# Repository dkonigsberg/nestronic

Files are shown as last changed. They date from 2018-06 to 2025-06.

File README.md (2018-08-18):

# Nestronic Game Music Synthesizer Alarm Clock

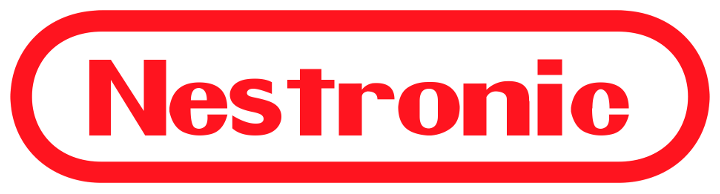
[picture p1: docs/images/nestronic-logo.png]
Nestronic


## Introduction

A good overview of the project can be found in these blog posts:
* [Introducing the Nestronic](http://hecgeek.blogspot.com/2018/02/nestronic-1.html)
* [Nestronic System Architecture](http://hecgeek.blogspot.com/2018/03/nestronic-2.html)
* [Building the Nestronic Prototype](http://hecgeek.blogspot.com/2018/05/nestronic-3.html)
* [Nestronic Input Board](http://hecgeek.blogspot.com/2018/07/nestronic-4.html)

A few videos demonstrating the project are here:
* [First end-to-end test](https://www.youtube.com/watch?v=97jic_WRrwY)
* [DuckTails!](https://www.youtube.com/watch?v=eafaFr9Q_rU)
* [First prototype assembled and working!](https://www.youtube.com/watch?v=izMFPKmD5ZU)
* [Completed case, buttons, and Blaster Master!](https://www.youtube.com/watch?v=pXp97wzkQEE)
* [Nestronic Complete Assembly](https://www.youtube.com/watch?v=UlO0NQTAaJU)

## Project Layout

### Hardware
The "hardware" directory contains [KiCad](http://kicad-pcb.org/) projects
with the complete circuit schematics, bill-of-materials, and
PCB layouts.

There are two circuit boards, the main board and the input board.
The main board contains the majority of the system, while the input
board handles buttons and anything else that needs to be placed on
the top shell of the enclosure.

### Software
The "software" directory contains all the source code for the firmware
that runs on the hardware. The "2a03" subdirectory contains code for
the RP2A03 CPU (a.k.a. NES APU), while the "esp32" subdirectory contains
code for the modern ESP32 microcontroller that drives the rest of the
system.

### Models
The "models" directory contains any CAD models and related resources
necessary to physically assemble the project. This may be sparse for now,
but will be filled out over time.

## Credits
ESP32 schematic symbols and footprints originally from:
https://github.com/adamjvr/ESP32-kiCAD-Footprints

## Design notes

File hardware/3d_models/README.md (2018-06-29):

# 3D Component Models

## Introduction

The 3D models used by the components in these schematics come from a variety
of sources. Some were created for this project, using KiCad's library
scripts and/or FreeCAD directly. Many others were downloaded from component
manufacturer websites.

Some manufacturers have a habit of freely distributing 3D models for their
components with attached notes saying that they shall not be redistributed.
These notes also often mention that the models are proprietary, confidential,
for personal use only, or something else that would scare you off from
actually admitting that you used them. As such, these models have not been
included in the project repository. Instead, link for downloading them
is provided.

The actual conversion of component models to WRL files is accomplished
with the [KiCad StepUp plugin](https://sourceforge.net/projects/kicadstepup/).

## Model List

The models are listed by base filename. Typical distribution files have
the ".step" extension, while the exported files have the ".wrl" extension.

To include models marked as not redistributable, download them from the
original source and convert using the KiCad StepUp plugin for FreeCAD.
Make sure the original and converted files have the same base name as
listed below.

Due to the incremental nature of project development, this list may include
models for components that are no longer part of the actual board design.

### B2B-PH-SM4-TB
* Status: Not included (Not redistributable)
* Source: http://www.jst-mfg.com/product/licensing_e.php?type=2&series=199&filename=B2B-PH-SM4-TB.zip

### BM06B-SRSS-TB
* Status: Not included (Not redistributable)
* Source: http://www.jst-mfg.com/product/licensing_e.php?type=2&series=231&filename=BM06B-SRSS-TB.zip

### SM06B-SRSS-TB
* Status: Not included (Not redistributable)
* Source: http://www.jst-mfg.com/product/licensing_e.php?type=2&series=231&filename=SM06B-SRSS-TB.zip

### DM3AT-SF-PEJM5
* Status: Not included (Not redistributable)
* Source: https://www.hirose.com/product/en/download_file/key_name/DM3AT-SF-PEJM5/category/Drawing%20(3D)(STEP)/doc_file_id/158358/?item_id=06090031000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

### BU2032SM-BT-GTR
* Status: Included (no terms listed with download)
* Source: http://www.memoryprotectiondevices.com/3d/download.php?pn=BU2032SM-BT-GTR

### CUI_PJ-058AH
* Status: Included (no terms listed with download)
* Source: https://www.cui.com/product/resource/digikey3dmodel/pj-058ah

### CUI_PJ-102AH
* Status: Included (no terms listed with download)
* Source: https://www.cui.com/product/resource/digikey3dmodel/pj-102ah

### P090S-04F15AR1MEG
* Status: Included (no terms listed with download)
* Source: http://www.ttelectronics.com/themes/ttelectronics/datasheets/3d/P090S-04F15AR1MEG.stp

### KiCAD-ESP-WROOM-32
* Status: Included (no terms listed with download)
* Source: https://grabcad.com/library/esp-wroom-32-3d-step-and-iges-models-1

### R-78E-0-5
* Status: Included (Same license as project)
* Source: Created for project using FreeCAD

### SLP4016P16_1.6x4mm_P0.5mm
* Status: Included (Same license as project)
* Source: Created for project using modified KiCad model scripts

### TSL251R
* Status: Included (Same license as project)
* Source: Created for project using FreeCAD

### SOIC-28W_8.636x18.491mm_P1.27mm
* Status: Included (Same license as project)
* Source: Created for project using modified KiCad model scripts

### AMS_TSL2591
* Status: Included (Same license as project)
* Source: Created for project using modified KiCad model scripts
* Notes: Matches general dimensions of component, but not appearance

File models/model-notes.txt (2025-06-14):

Top
---
Positioning touch pad:
X = -1.965 mm
Y = -24.04 mm

Front panel DXF
---------------
Display center is is 6.049mm above panel center
Bezel is 28.46mm (vertical) from panel center

Hardware
--------
Base:
94180A333 x 4
	Heat-Set Inserts for Plastics
	M3 x 0.5 mm Thread Size, 6.4 mm Installed Length
94180A321 x 4
	Heat-Set Inserts for Plastics
	M2.5 x 0.45 mm Thread Size, 3.4 mm Installed Length
92005A118 x 4
	Steel Pan Head Phillips Screw
	M3 x 0.5 mm Thread, 8 mm Long
91166A210 x 4
	Zinc-Plated Steel Washer
	for M3 Screw Size, 3.2 mm ID, 7 mm OD
91420A016 x 4
	Steel Phillips Flat Head Screws
	M2.5 x 0.45 mm Thread, 6 mm Long

Top:
94180A331 x 8
	Heat-Set Inserts for Plastics
	M3 x 0.5 mm Thread Size, 3.8 mm Installed Length
94180A321 x 1
	Heat-Set Inserts for Plastics
	M2.5 x 0.45 mm Thread Size, 3.4 mm Installed Length
92005A116 x 8
	Steel Pan Head Phillips Screw
	M3 x 0.5 mm Thread, 6 mm Long
92005A061 x 1
	Steel Pan Head Phillips Screw
	M2.5 x 0.45 mm Thread, 5 mm Long
91166A210 x 8
	Zinc-Plated Steel Washer
	for M3 Screw Size, 3.2 mm ID, 7 mm OD

Connection:
94180A333 x 4
	Heat-Set Inserts for Plastics
	M3 x 0.5 mm Thread Size, 6.4 mm Installed Length
92005A118 x 4
	Steel Pan Head Phillips Screw
	M3 x 0.5 mm Thread, 8 mm Long

Standard Dimensions
-------------------
M3 x L6.4mm inserts (94180A333)
	Hole diameter: 5.31 mm (M3_L6_4mm_diameter)
	Depth: 6.4 mm (M3_L6_4mm_depth)
	Taper angle: -2.371 deg (M3_L6_4mm_taper)

M3 x L3.8mm inserts (94180A331)
	Hole diameter: 0.213 in (M3_L3_8mm_diameter)
	Depth: 0.157 in (M3_L3_8mm_depth)
	Taper angle: -3.16 deg (M3_L3_8mm_taper)

M2.5 x L3.4mm inserts (94180A321)
	Hole diameter: 0.163 in (M2_5_L3_4mm_diameter)
	Depth: -3.4 mm (M2_5_L3_4mm_depth)
	Taper angle: -2.021 deg (M2_5_L3_4mm_taper)

Printing Notes
--------------
All parts printed on the Ultimaker 3
Prints secured to bed with Magigoo
0.4mm nozzle, unless specified otherwise

All parts, except the thumbwheel, need a 90 degree rotation in Cura
to print with the correct orientation.

base.stl
	- Atomic Filament 2.85mm Gray PLA
	- Ultimaker Breakaway Material (supports)
	- Layer Height: 0.1
	- Infill: 20%
	- Supports: yes (breakaway)
	- Print time: 01d 12h 50min
	- Material used: 116g

top.stl / top-touchpad.stl
	- Touchpad offset: Y = -14.9938 mm
	- Atomic Filament 2.85mm Light Gray v2 PLA (top)
	- Proto-Pasta 2.85mm Conductive PLA (touchpad)
	- Infill: 20%
	- Supports: yes (light gray)

bezel.stl
	- Ultimaker Red PLA
	- Layer Height: 0.1mm
	- Infill: 20%
	- Supports: no

top-speaker-gasket.stl
	- Ultimaker Black TPU 95A
	- Layer Height: 0.2mm
	- Infill: 20%
	- Supports: no

thumbwheel.stl
	- Nozzle: AA 0.25mm
	- Ultimaker Black PLA
	- Layer Height: 0.1mm
	- Infill: 20%
	- Supports: no

button_4way.stl
	- Nozzle: AA 0.25mm
	- Ultimaker Black PLA
	- Layer Height: 0.06mm
	- Infill: 100%
	- Supports: no

button_select.stl (x2)
	- Nozzle: AA 0.25mm
	- Ultimaker Black PLA
	- Layer Height: 0.06mm
	- Infill: 100%
	- Supports: no

button_ab.stl (x2)
	- Nozzle: AA 0.25mm
	- Ultimaker Red PLA
	- Layer Height: 0.06mm
	- Infill: 100%
	- Supports: no

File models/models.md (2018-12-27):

# Nestronic Enclosure Models

## Introduction

This directory contains all the assets necessary to produce the physical
enclosure for the Nestronic. This document explains how to use those
assets, and ultimately how to assemble the enclosure.

## Electronics

### Main Board

The assets for the main circuit board are contained within the "main-board"
project under the top-level "hardware" directory. This board is installed
into the base of the enclosure.

### Input Board

The assets for the input circuit board are contained within the "input-board"
project under the top-level "hardware" directory. This board is installed
into the top of the enclosure.

### Display Module

* Newhaven Display Graphic OLED
* Part number:
    NHD-3.12-25664UCW2 (white),
    NHD-3.12-25664UCB2 (blue), or
    NHD-3.12-25664UCY2 (yellow)
* 3.12" diagonal, 256x64 pixels
* Reference: http://www.newhavendisplay.com/nhd31225664ucw2-p-9583.html
* _**Note:** You will need to solder a 20-pin header onto the display module,
  and will also need to procure a short cable to connect it to a matching
  pin header on the main board._

### Speaker

* CUI Inc. Standard Size Speaker
* Part number: CSS-66668N
* 3.0 W, 8 Ohm, Neodymium Magnet, Paper Cone
* Reference: https://www.cui.com/product/audio/speakers/standard-(41-mm~205-mm)/css-66668n
* _**Note:** You will need to solder a cable with a JST-PH 2-pin plug onto
  the speaker's terminals. One convenient source for this is sold by
  Adafruit as a [battery extension cable](https://www.adafruit.com/product/1131)
  that you can cut the socket off of._

### Connector Cable

* JST Inc. Jumper Cable
* Part number: A06SR06SR30K152B
* JUMPER 06SR-3S - 06SR-3S 6"
* Digi-Key Part number: 455-3015-ND

## Mechanical Hardware

The mechanical hardware is specified in terms of parts that are orderable
from the [McMaster-Carr](https://www.mcmaster.com/) catalog. For the heat-set
inserts, it is probably best to stick to these exact parts. For the other
components, anything of similar specifications should work.

### Heat-Set Inserts
* **Heat-Set Inserts for Plastics**
    * M3 x 0.5 mm Thread Size, 6.4 mm Installed Length
    * Part: 94180A333
    * Quantity: 8
* **Heat-Set Inserts for Plastics**
    * M3 x 0.5 mm Thread Size, 3.8 mm Installed Length
    * Part: 94180A331
    * Quantity: 8
* **Heat-Set Inserts for Plastics**
    * M2.5 x 0.45 mm Thread Size, 3.4 mm Installed Length
    * Part: 94180A321
    * Quantity: 5

### Screws
* **Steel Pan Head Phillips Screw**
    * M3 x 0.5 mm Thread, 8 mm Long
    * Part: 92005A118
    * Quantity: 8
* **Steel Pan Head Phillips Screw**
    * M3 x 0.5 mm Thread, 6 mm Long
    * Part: 92005A116
    * Quantity: 8
* **Steel Phillips Flat Head Screws**
    * M2.5 x 0.45 mm Thread, 6 mm Long
    * Part: 91420A016
    * Quantity: 4
* **Steel Pan Head Phillips Screw**
    * M2.5 x 0.45 mm Thread, 5 mm Long
    * Part: 92005A061
    * Quantity: 1

### Miscellaneous
* **Zinc-Plated Steel Washer**
    * For M3 Screw Size, 3.2 mm ID, 7 mm OD
    * Part: 91166A210
    * Quantity: 8-12
* **Polyethylene Foam Adhesive-Back Bumper**
    * 1/2" OD, 1/8" High
    * Part: 8213K4
    * Quantity: 4
    * _**Note:** Nonslip rubber bumper 8771K81 may alternatively be used._

## 3D Printed Components

The prototype enclosure was printed on an [Ultimaker 3](https://ultimaker.com/en/products/ultimaker-3) using [Cura](https://ultimaker.com/en/products/ultimaker-cura-software) as the slicer.
The print bed was prepared with [Magigoo](https://magigoo.com/) to ensure
bottom layer adhesion during the printing process.
All parts, except for the thumbwheel, need a 90 degree rotation in Cura to
print with the correct orientation.

### Enclosure Shell
These components were printed using a standard 0.4mm AA nozzle, and will
probably look fine if printed with a lower level of detail than specified.

* **Base** (base.stl)
    * Extruder 1: Atomic Filament 2.85mm Gray PLA
    * Extruder 2: Ultimaker Breakaway Material
    * Layer Height: 0.15mm
    * Infill: 20%
    * Supports: yes (Extruder 2)
    * _**Note:** Using a prime tower is highly recommended as a way to reduce
      any oozing caused by the support material."_

* **Top** (top.stl, top-touchpad.stl)
    * Extruder 1: Atomic Filament 2.85mm Light Gray v2 PLA
    * Extruder 2: Proto-Pasta 2.85mm Conductive PLA
    * Layer Height: 0.15mm
    * Infill: 20%
    * Supports: yes (Extruder 1)
    * Print the top model with extruder 1.
    * Print the top-touchpad model with extruder 2 and a Y offset of
      11.935 mm.
    * _**Note:** The conductive PLA material can print on the messy side.
      Using a prime tower is highly recommended, however some residual mess
      is inevitable."_

* **Front Bezel** (bezel.stl)
    * Material: Ultimaker Red PLA
    * Layer Height: 0.1mm
    * Infill: 20%
    * Supports: no

* **Speaker Gasket** (top-speaker-gasket.stl)
    * Material: Ultimaker Black TPU 95A
    * Layer Height: 0.2mm
    * Infill: 20%
    * Supports: no

### Enclosure Fittings
These components were printed using a 0.25mm AA nozzle, and should ideally be
printed with the highest level of detail that your printer is capable of.

* **Thumbwheel** (thumbwheel.stl)
    * Material: Ultimaker Black PLA
    * Layer Height: 0.06mm
    * Infill: 20%
    * Supports: no

* **4-Way Button** (button_4way.stl)
    * Material: Ultimaker Black PLA
    * Layer Height: 0.06mm
    * Infill: 100%
    * Supports: no

* **Start/Select Button** (button_select.stl)
    * Print quantity: 2
    * Material: Ultimaker Black PLA
    * Layer Height: 0.06mm
    * Infill: 100%
    * Supports: no

* **A/B Buttons** (button_ab.stl)
    * Print quantity: 2
    * Material: Ultimaker Red PLA
    * Layer Height: 0.06mm
    * Infill: 100%
    * Supports: no

## Front Panel

The front panel was ordered from [Beta Layout](https://us.beta-layout.com/frontpanel/)
in clear acrylic, using their provided design software. The data file is also located in this directory ("front-panel.T3000").

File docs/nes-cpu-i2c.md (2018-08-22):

NES CPU I2C Protocol
====================

Communication between the ESP32 and the NES CPU (RP2A03) happens via the I2C
protocol. On the ESP32 side, the built-in I2C controller is used to act as a
master. On the NES CPU side, a PCI9564 controller IC is used to act as a slave.
This document describes the specifics of the I2C protocol implemented in the
firmware on the NES CPU.

Writing to the device
---------------------
The NES CPU listens as a slave at 7-bit address $08.
To write to it, this typical patten is followed:

    +---+---+---+---+---+---+---+---+---+---+
    | S | 0 | 0 | 0 | 1 | 0 | 0 | 0 |R/W| A |
    +---+---+---+---+---+---+---+---+---+---+
Send the start condition, the 7-bit slave address, and the read/write bit,
followed by an ack.

    +---+---+---+---+---+---+---+---+---+
    | B7| B6| B5| B4| B3| B2| B1| B0| A |
    +---+---+---+---+---+---+---+---+---+

Send the 8-bit register address, followed by an ack.

    +---+---+---+---+---+---+---+---+---+---+
    | D7| D6| D5| D4| D3| D2| D1| D0| A | P |
    +---+---+---+---+---+---+---+---+---+---+

Send the 8-bit data byte, followed by an ack and a stop condition.

Register map
------------

    +------+---------------+-----+-----+-----+-----+-----+-----+-----+-----+
    | Addr | Register Name |Bit 7|Bit 6|Bit 5|Bit 4|Bit 3|Bit 2|Bit 1|Bit 0|
    +------+---------------+-----+-----+-----+-----+-----+-----+-----+-----+
    |  $00 |               |                                               |
    |  ... | NES APU   (W) | See below                                     |
    |  $15 |               |                                               |
    +------+---------------+-----+-----+-----+-----+-----+-----+-----+-----+
    |  $16 | OUTPUT  (R/W) |APUI | N/A | N/A | N/A | N/A |OUT2 |OUT1 |OUT0 |
    +------+---------------+-----+-----+-----+-----+-----+-----+-----+-----+
    |  $17 | NES APU   (W) | See below                                     |
    +------+---------------+-----+-----+-----+-----+-----+-----+-----+-----+
    |  $7F | CONFIG  (R/W) | N/A | N/A | N/A | N/A | N/A | N/A | N/A | N/A |
    +------+---------------+-----+-----+-----+-----+-----+-----+-----+-----+
    |  $88 |               |                                               |
    |  ... | DATA    (R/W) | See below                                     |
    |  $FF |               |                                               |
    +------+---------------+-----+-----+-----+-----+-----+-----+-----+-----+

Note: Unsupported registers are simply ignored by the firmware.

### OUTPUT Register ($16)

OUTPUT Register Bits:
    APUI: APU Initialize; 1 to reinitialize the APU (W)
    OUT0: Audio amplifier control; 0 to disable, 1 to enable (R/W)

### NES CPU Registers ($00-$15, $17)

The following APU registers are directly mapped to addresses corresponding to
the lower byte of the APU register address: (e.g. $4010 -> $10)

    APU_PULSE1CTRL  = $4000         ; Pulse #1 Control Register (W)
    APU_PULSE1RAMP  = $4001         ; Pulse #1 Ramp Control Register (W)
    APU_PULSE1FTUNE = $4002         ; Pulse #1 Fine Tune (FT) Register (W)
    APU_PULSE1CTUNE = $4003         ; Pulse #1 Coarse Tune (CT) Register (W)
    APU_PULSE2CTRL  = $4004         ; Pulse #2 Control Register (W)
    APU_PULSE2RAMP  = $4005         ; Pulse #2 Ramp Control Register (W)
    APU_PULSE2FTUNE = $4006         ; Pulse #2 Fine Tune Register (W)
    APU_PULSE2STUNE = $4007         ; Pulse #2 Coarse Tune Register (W)
    APU_TRICTRL1    = $4008         ; Triangle Control Register #1 (W)
    APU_TRICTRL2    = $4009         ; Triangle Control Register #2 (?)
    APU_TRIFREQ1    = $400A         ; Triangle Frequency Register #1 (W)
    APU_TRIFREQ2    = $400B         ; Triangle Frequency Register #2 (W)
    APU_NOISECTRL   = $400C         ; Noise Control Register #1 (W)
    APU_UNUSED      = $400D         ; Unused (???)
    APU_NOISEFREQ1  = $400E         ; Noise Frequency Register #1 (W)
    APU_NOISEFREQ2  = $400F         ; Noise Frequency Register #2 (W)
    APU_MODCTRL     = $4010         ; Delta Modulation Control Register (W)
    APU_MODDA       = $4011         ; Delta Modulation D/A Register (W)
    APU_MODADDR     = $4012         ; Delta Modulation Address Register (W)
    APU_MODLEN      = $4013         ; Delta Modulation Data Length Register (W)
    APU_CHANCTRL    = $4015         ; Sound/Vertical Clock Signal Register (R/W)
    APU_PAD2        = $4017         ; Joypad #2/SOFTCLK (W)

### CONFIG Register

This register is currently an unused region of memory that can be both
read from and written to. It can be used to implement a basic interface test.

### Data Registers ($88-$FF)

These registers are used to write bulk data to a region of RAM that
corresponds to the address range $C200-$DFFF. Each value corresponds to the
start of a 64-byte block within that range.
To write bulk data, first send the start address, then start sending data
bytes. Each byte will increment the address offset, up to a maximum of 256
bytes.

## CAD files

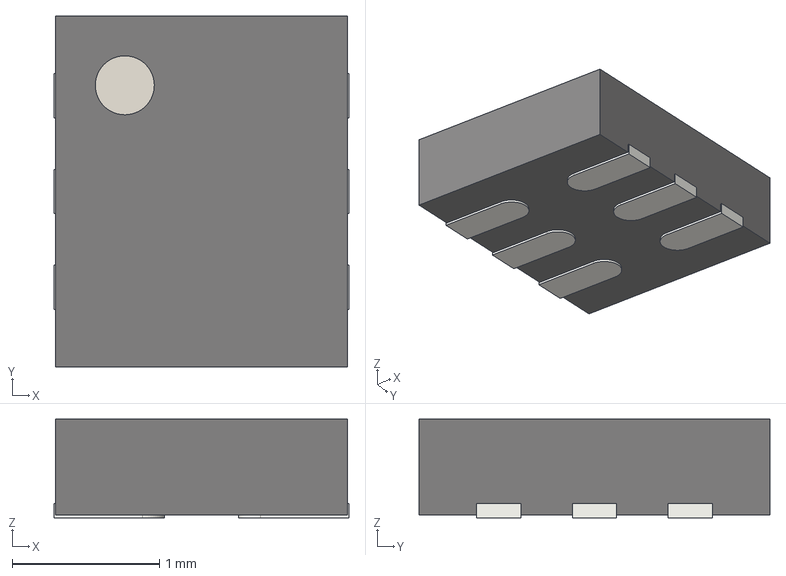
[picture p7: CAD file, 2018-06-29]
hardware/3d_models/AMS_TSL2591.step
2.00 x 2.38 x 0.67 mm

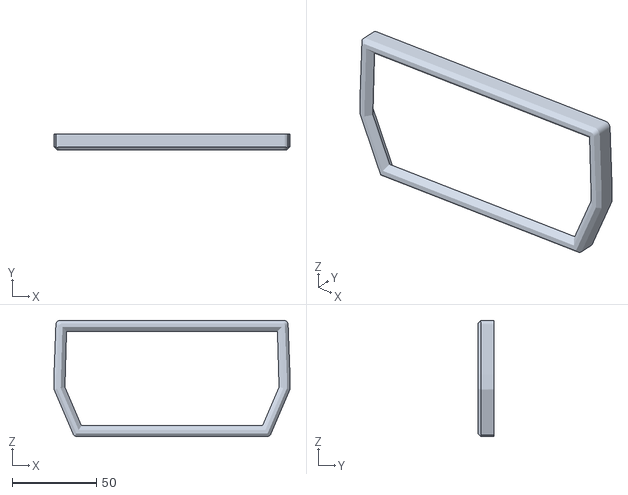
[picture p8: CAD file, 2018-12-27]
models/bezel.stl
140.0 x 9.60 x 69.0

software/esp32/components/u8g2/sys/arduino/u8g2_full_buffer/SwitchBox/board.dxf
60
40
52
8
24
80
30
32
25
100
190
4
12
6
14

software/esp32/components/u8g2/sys/arm/stm32l031x6/clock.dxf
65
32
28
16
Draufsicht
Vorderansicht
von unten
von rechts
von links
14
6
45
60
30
20
8
35
75
55
10
12

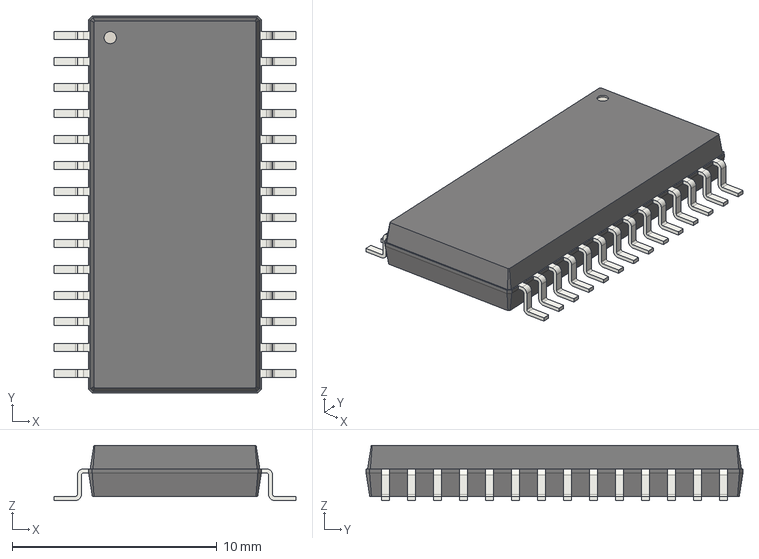
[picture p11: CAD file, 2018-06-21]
hardware/3d_models/SOIC-28W_8.636x18.491mm_P1.27mm.step
11.8 x 18.4 x 2.69 mm

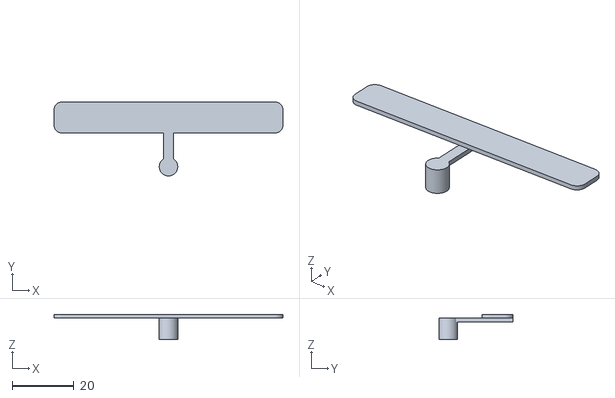
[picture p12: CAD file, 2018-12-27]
models/top-touchpad.stl
74.0 x 23.9 x 8.08

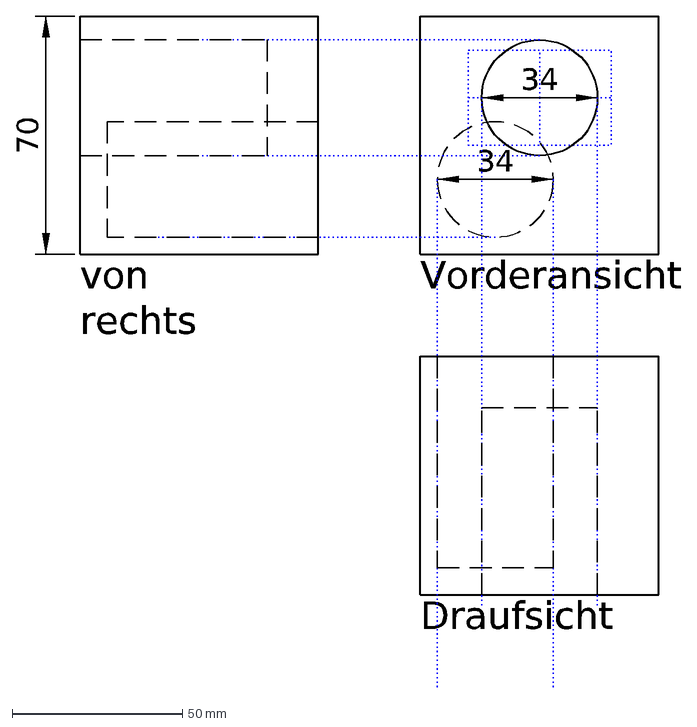
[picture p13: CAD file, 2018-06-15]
software/esp32/components/u8g2/sys/arm/stm32l031x6/clock_cube.dxf
Draufsicht
Vorderansicht
von rechts
70
34

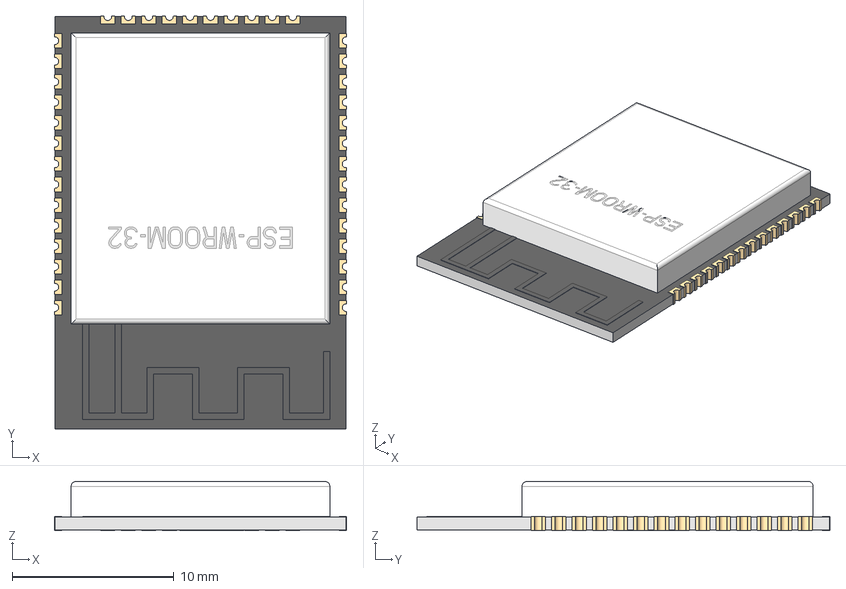
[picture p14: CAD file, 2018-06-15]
hardware/3d_models/KiCAD-ESP-WROOM-32.step
18.1 x 25.5 x 3.04 mm

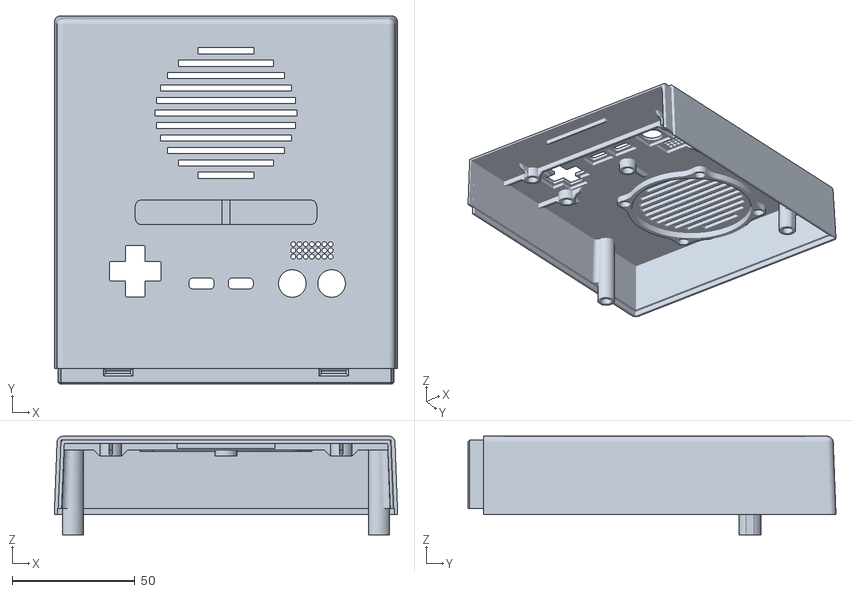
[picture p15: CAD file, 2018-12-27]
models/top.stl
140.0 x 150.0 x 40.2

software/esp32/components/u8g2/sys/arm/stm32l031x6/clock_2.dxf
65
Draufsicht
Vorderansicht
von unten
von rechts
von links
14
30
32
35
75
55
10
12
16
11
22
34
28
29
18
93
19
43
15
68
60
57
150
Holzbohrer: 2.5, 8, 10, 12, 16, 32mm
8
7
6
2.5mm

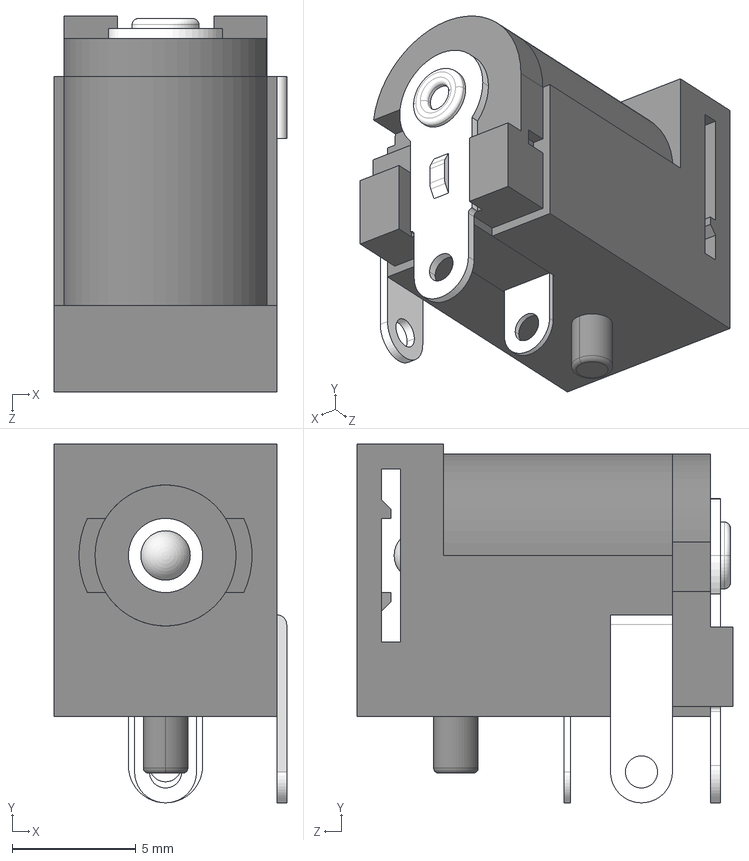
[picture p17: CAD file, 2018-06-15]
hardware/3d_models/CUI_PJ-058AH.step
9.40 x 14.5 x 15.2 mm

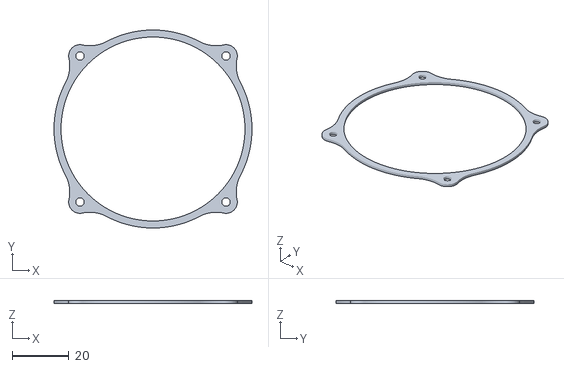
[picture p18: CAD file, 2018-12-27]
models/top-speaker-gasket.stl
70.0 x 70.0 x 1.00

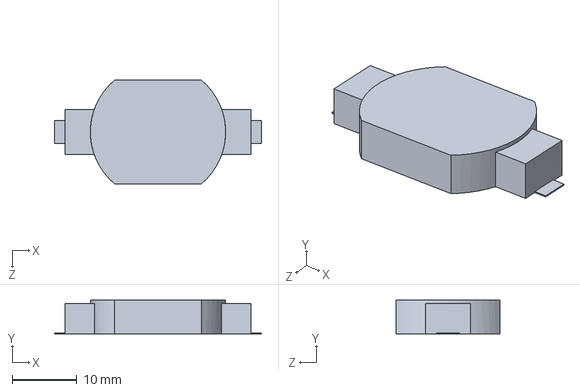
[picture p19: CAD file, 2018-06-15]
hardware/3d_models/BU2032SM-BT-GTR.step
31.9 x 5.20 x 16.0 mm

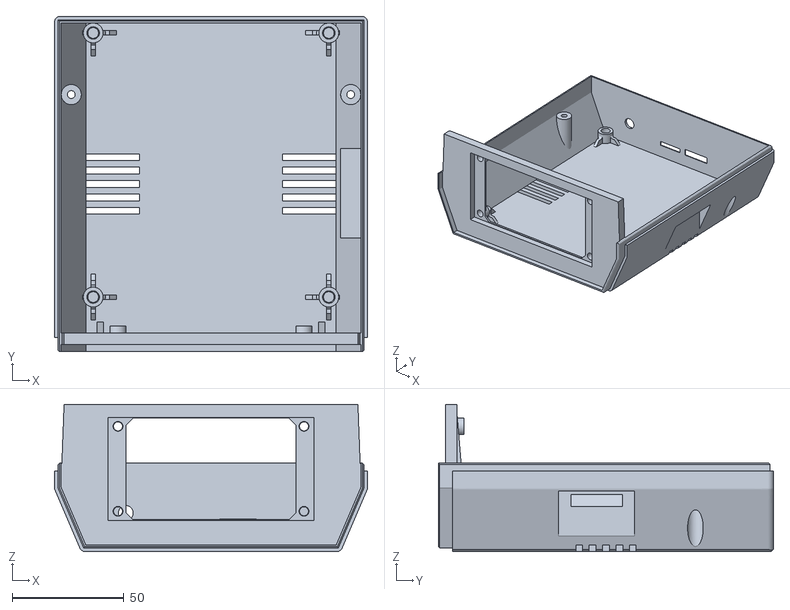
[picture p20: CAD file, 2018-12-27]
models/base.stl
140.0 x 150.0 x 65.8

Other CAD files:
hardware/3d_models/CUI_PJ-102AH.step
models/button_ab.step
hardware/3d_models/SLP4016P16_1.6x4mm_P0.5mm.step
models/button_4way.step
hardware/3d_models/AMS_TSL2591.FCStd
hardware/3d_models/P090S-04F15AR1MEG.fcstd
hardware/3d_models/P090S-04F15AR1MEG.stp
hardware/3d_models/R-78E-0-5.fcstd
hardware/3d_models/R-78E-0-5.step
hardware/3d_models/SOIC-28W_8.636x18.491mm_P1.27mm.FCStd
hardware/3d_models/TSL251R.fcstd
hardware/3d_models/TSL251R.step
models/button_4way.f3d
models/button_4way.stl
models/button_ab.f3d
models/button_ab.stl
models/button_select.f3d
models/button_select.step
models/button_select.stl
models/thumbwheel.fcstd
models/thumbwheel.step
models/thumbwheel.stl

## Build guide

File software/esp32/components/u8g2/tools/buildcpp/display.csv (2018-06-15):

# 1. device name
# 2. pinset
# 3. constructor name w/o prefix
u8x8_d_ssd1306_128x64_noname | 4WSWSPI | SSD1306_128X64_4W_SW_SPI
u8x8_d_ssd1306_128x64_noname | 4WHWSPI | SSD1306_128X64_4W_HW_SPI
u8x8_d_ssd1306_128x64_noname | 3WSWSPI | SSD1306_128X64_3W_SW_SPI
u8x8_d_ssd1306_128x64_noname | SSDSWI2C | SSD1306_128X64_SW_I2C
u8x8_d_ssd1306_128x64_noname | 6800 | SSD1306_128X64_6800
u8x8_d_ssd1306_128x64_noname | 8080 | SSD1306_128X64_8080

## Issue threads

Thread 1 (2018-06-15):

Tweak footprint for U7 (AS6C6264)

dkonigsberg, 2018-06-15:
The actual AS6C6264 IC is slightly wider than the footprint currently being used. While it can still fit, the PCB footprint should be changed to a slightly wider one.

Closed 2018-06-21.

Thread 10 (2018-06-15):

Add an ambient light sensor with an I2C interface to the input board

dkonigsberg, 2018-06-15:
The best place for an ambient light sensor is the input board, where it can see out the top of the case. Due to available interfaces at this location, that sensor is best connected via I2C.

Need to experiment with sensors through a 3D printed grid-hole pattern, which can be added to the top of the enclosure, before committing to this change.

A likely location is right above the A/B buttons, since that is where the board space can be most easily made available.

dkonigsberg, 2018-06-29:
Right now it looks like this sensor is likely to be the TSL2591. Bought the breakout board from Adafruit, and placed it inside a 3D printed simulation of what the real enclosure will be like. Its sensitive enough to provide meaningful data in this configuration, so it should work just fine.

Closed 2018-06-29.

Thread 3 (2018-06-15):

Change U8 (MCP40D17) Vdd from 3.3V to 5V

dkonigsberg, 2018-06-15:
The voltage passing through the variable resistor pins may exceed 3.3V under certain circumstances, which would put the chip out of spec and possibly destroy it. Switching this IC to the 5V supply resolves the issue.

Additionally, the datasheet mentions Schmitt triggered inputs on the I2C pins. This might cause issues with a 3.3V I2C bus when on a 5V supply, but these issues have not been seen in testing. If they ever manifest, the Analog Devices AD5246 is an option as a drop-in replacement.

dkonigsberg, 2018-06-20:
Fixed by: a221505df55226e8c0a0a7a35ac3c3a8b6f16773

Closed 2018-06-20.

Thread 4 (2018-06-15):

Change amplifier gain resistor (R14) from 20k to 10k or lower

dkonigsberg, 2018-06-15:
We still need this resistor to enforce a minimum gain on the audio amplifier, but 20k is way too high of a value.

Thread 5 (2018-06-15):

Fix pin mappings on Q1/Q2/Q3

dkonigsberg, 2018-06-15:
The pin mappings between the schematic symbol and the PCB footprint for these components is backwards. To kludge them into working on the Rev A PCB, these transistors had to be reinstalled upside-down.

This should be fixed on the schematic and PCB layout.

Closed 2018-06-21.

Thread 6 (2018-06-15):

Move TP1 over to GPIO27

dkonigsberg, 2018-06-15:
TP1 is intended to be used for ADC calibration, however is it currently on a pin that has a pull-up resistor installed on the main board. This makes it useless.
It should be moved to GPIO27, which doesn't have a pull-up resistor on the main board. It'll still only be usable if the input board is disconnected, but that is fine for a special-purpose test point.

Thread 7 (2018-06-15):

Modify SRAM address decoding to mirror it onto address $C000

dkonigsberg, 2018-06-15:
The NES APU requires addressable memory at $C000 for [DMC/DMA](https://wiki.nesdev.com/w/index.php/APU_DMC) playback of PCM samples. The current design has no memory at that address.

The easiest way of doing this is to mirror the existing SRAM chip onto that address. This can probably be done by using a spare NAND gate from U10 as glue between the address decoder (U5) and the non-inverting enable line (CE2) of the SRAM chip (U7).

Closed 2018-06-23.

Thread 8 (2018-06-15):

Add the ability to reset the PCA9564 I2C controller from the RP2A03

dkonigsberg, 2018-06-15:
Several of the documented fault conditions with the PCA9564 can only be resolved by toggling its RESET pin. This may be do-able using another one of the OUT pins on the RP2A03, possibly combined with a pull-up resistor.

This needs lab testing before implementation, because the levels on those pins can be weird and the PCA9564 is a 3.3V component (albeit 5V tolerant).

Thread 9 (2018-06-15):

Remove the ambient light sensor (U14) from the main board

dkonigsberg, 2018-06-15:
This sensor is terrible at actually detecting ambient light when the board is installed in an enclosure. There doesn't seem to be a practical resolution, other than moving/changing the sensor. The component (TSL251R) is also now discontinued, so its better to just remove it in favor of something else.

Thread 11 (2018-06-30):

Integrate USB<->Serial chip into main board

dkonigsberg, 2018-06-30:
The current design requires an external USB-to-serial dongle, that exposes the RTS/DTR lines, for programming. While a common item, it is still an annoying extra item to have to keep around.

Furthermore, a portion of the programming circuit (the bootstrapping transistors) is already on the main board, as it is specific to the ESP32.

To make things easier to work with in the long term, one idea is to directly integrate a CP2102 chip onto the main board, along with the necessary support components (USB connector, TVS protection, etc). There is space for this, and doing so would effectively replace the 6-pin header on the back of the device with a simple USB port.

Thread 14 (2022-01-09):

Plans to finish full NSF playback implementation?

sofakng, 2022-01-09:
I was extremely excited to see this project because it seems to be the closest implementation of a hardware-based NES music player but it seems like the NSF playback function isn't 100% complete?

Are there plans to finish the implementation?

I've heard that VGM files don't have the 100% information for completely accurate playback but NSF does.

dkonigsberg, 2022-01-09:
VGM and NSF are different styles of format. VGM is basically a "recording" of the commands being sent to the audio synth hardware, whereas NSF is actually a rip of the code that generates those commands. I'm not sure what limitations of VGM you've heard of specifically.

The real issue with the NSF support right now has to do with the playback of sample data ([APU DMC](https://wiki.nesdev.org/w/index.php?title=APU_DMC)) that some games use. It needs to be loaded in advance of being played, obviously, and the NES CPU doesn't have enough RAM to pre-load all the data that could theoretically be there.

With VGM, I can pre-analyze use of all the audio sample data in the track and decide when/how to load it into the NES CPU's memory space (0ab51e1f31eb3a67d4754d60677abc206d0d6d5c). This was quite complicated to do, but it works.

With NSF, there's really no easy way to do this because NSF is more of a "program" and less of a "data format". The only way to realistically pull it off would be to either re-engineer the Nestronic to give the NES CPU a lot more RAM and simulated mapper hardware, or to emulate a 6502 on the ESP32 side significantly faster than playback speed so I could sneak data loading within the playback process.

sofakng, 2022-01-09:
Thank you so much for the detailed response!

I've spoken to Jose Tejada who is an FPGA developer (MiSTer project, etc) and has created FPGA implementations of many sound chips including YM2203, YM2612, YM2610 and YM2151.  I asked him about developing an FPGA-based VGM player and this was his response:

> I am afraid that these formats are actually rather inaccurate. They were designed with a fixed sample rate of data commands at 44kHz. This adds jitter to the sound phase, I am not sure how noticeable it is. Almost no actual system was sending data at 44kHz. Double Dragon, for instance, sends it at some submultiple of 3.57MHz. It is even worse for some PCM encoding systems such as Megadrive's because VGM effectively resamples the data and creates some noise artifacts.

I didn't ask about the NES specifically so I'm not sure if this applies or not.  However, I'd love to hear your feedback or information.

Regardless, I think this is an absolutely fantastic project and I really appreciate how much work you've devoted to this!

dkonigsberg, 2022-01-09:
There is probably some truth to that gripe. However, I'm going to put this into the category of "problems that likely don't matter" because you're not directly playing audio samples at that rate. You're just sending commands to audio synth hardware at a much coarser rate, and its doing the business.  In the context of the NES and VGM playback, 44.1kHz is really just the time base that is used to calculate delays between commands (when specified in the VGM data).

Besides, the whole architecture of the Nestronic is really not capable of doing direct NSF (or clock-cycle-perfect) playback anyways. Its designed around determining that directly sending APU commands to the NES CPU at a slower rate was good enough to produce audio that (to a human ear) was close to perfect. I really designed it around VGM, so the NSF player is actually running a 6502 emulator on the ESP32 side and essentially generating VGM-style data on the fly.

FWIW, I've played audio tracks from the modern chiptune game ["Shovel Knight"](https://www.yachtclubgames.com/games/shovel-knight-treasure-trove), which supplies an NSF version of the soundtrack, and it can keep up just fine. This game's soundtrack generates audio commands at a much higher data rate than any real NES game, so it makes for a good stress test.

In order to make something that could do cycle-accurate NSF playback, I'd have to completely re-engineer the device so that the NES CPU could run the NSF code directly.  (Probably with a significantly larger SRAM on the NES CPU, and an FPGA in-between, rather than simply having the NES CPU run a program that communicates with the ESP32 to receive audio commands.)

sofakng, 2022-01-09:
I'm a big fan of Shovel Knight and had no idea it supplies NSF soundtracks but that is very interesting.

You're answered my question(s) so we can close this comment, but I did have a related (somewhat off-topic) question:

Does Nestronic (ie. VGM format) support games that used mapper hardware?  (ie. VRC6, etc)

You briefly mentioned this above, but if I understand correctly NSF playback would require mapper hardware (or emulated) to process those 6502 instructions, but VGM playback already has them "processed" and is the recorded output from the mappers, etc?

dkonigsberg, 2022-01-09:
> Does Nestronic (ie. VGM format) support games that used mapper hardware? (ie. VRC6, etc)

So the mappers do two things:
1. Provide a way for NES code to address more ROM than a 16-bit memory address space would otherwise allow
2. Add additional "expansion audio" hardware, but only on the Famicom (not the NES)

Nestronic can play VGM files from games that use mapper hardware (which is most of them), because juggling all of that is done on the ESP32 side. What it cannot do, is play "expansion audio" generated by extra hardware those mappers may contain (e.g. VRC6), because it doesn't contain that hardware. In order to do that, I'd need to add an FPGA or a collection of salvaged mapper chips.

> You briefly mentioned this above, but if I understand correctly NSF playback would require mapper hardware (or emulated) to process those 6502 instructions, but VGM playback already has them "processed" and is the recorded output from the mappers, etc?

Playing NSF directly on the NES CPU (2A03) would require emulating the mapper hardware, because playing NSF is basically just running NES code on a headless NES emulator. So you'd need to emulate the memory model that would be available to a NES.

VGM playback avoids this, because VGM is just a stream of NES APU (audio hardware) commands. So its already "processed" and thus doesn't care what the memory model of the NES looks like.

sofakng, 2022-01-09:
Got it.  I wasn't sure how the audio expansion chips worked and thought they might have generated additional APU instructions but it sounds like generated the actual sound which was mixed into the APU-generated sound.

I'm just curious (and again I realize this isn't directly related to the Nestronic so I apologize), but does the NES VGM format include any expansion audio data?  If I understand correctly, this would have to be data captured from the expansion audio chips (ie. VRC6) and perhaps not possible?

dkonigsberg, 2022-01-09:
> it sounds like generated the actual sound

Yes, some mapper chips contain additional sound generation hardware. The Famicom had a connection to link it back to the console's audio output. The NES didn't.

> does the NES VGM format include any expansion audio data?

It does. I've stumbled across VGM files from games that have it.

sofakng, 2022-01-09:
Thanks so much for the help and the information!

Closed 2022-01-09.

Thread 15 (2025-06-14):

About the firmware

hualazimo7, 2025-06-14:
Can you upload the hex or bin file for the eeprom and esp32? I have problem programming those two chips by command-line tools.
Thank you a lot, looking forwark for your reply.

dkonigsberg, 2025-06-14:
I haven't built this project in a long time, so it would take some work to get it all building again with the latest ESP-IDF.
However, I did find the binaries from my last build sitting around on my computer, so I've posted it as a release here:
https://github.com/dkonigsberg/nestronic/releases/tag/latest-2020

Closed 2025-06-14.

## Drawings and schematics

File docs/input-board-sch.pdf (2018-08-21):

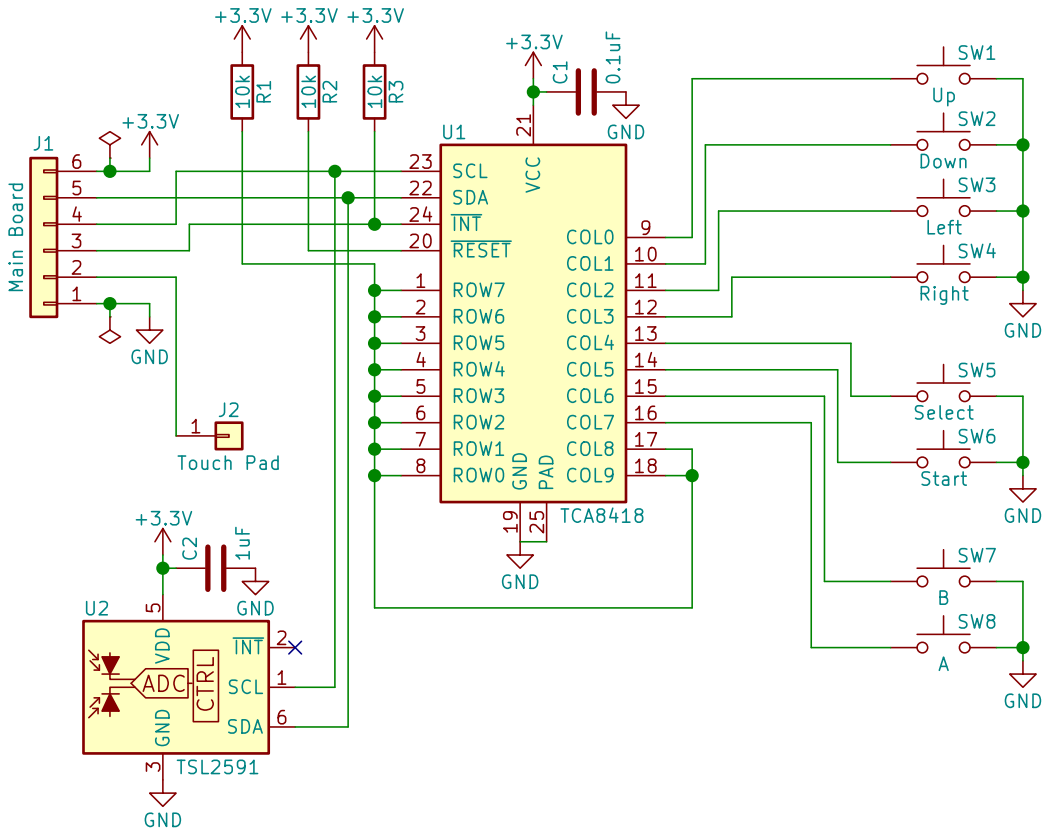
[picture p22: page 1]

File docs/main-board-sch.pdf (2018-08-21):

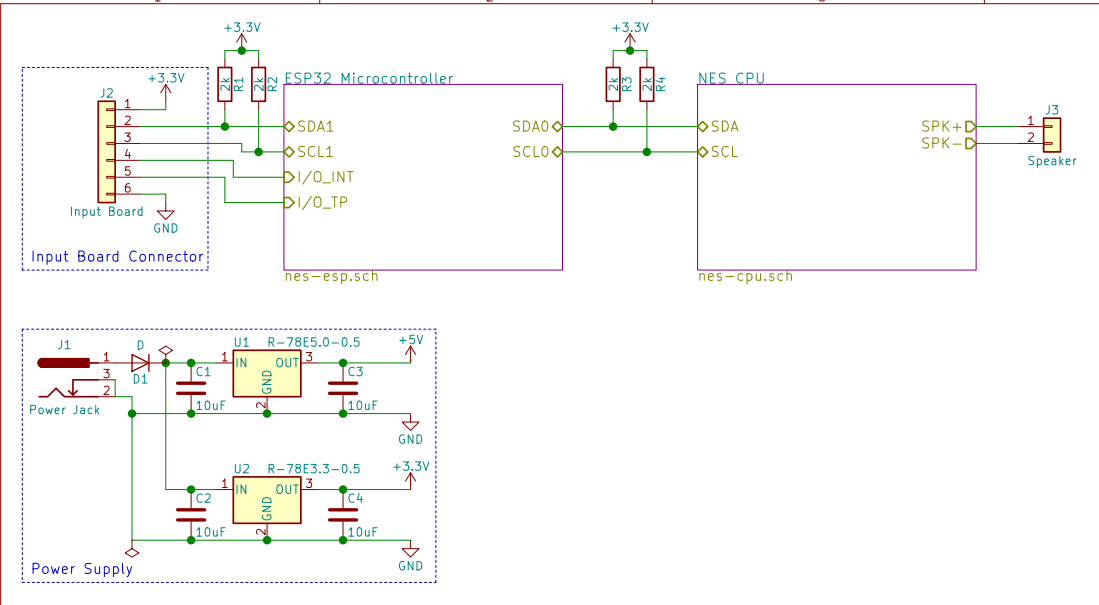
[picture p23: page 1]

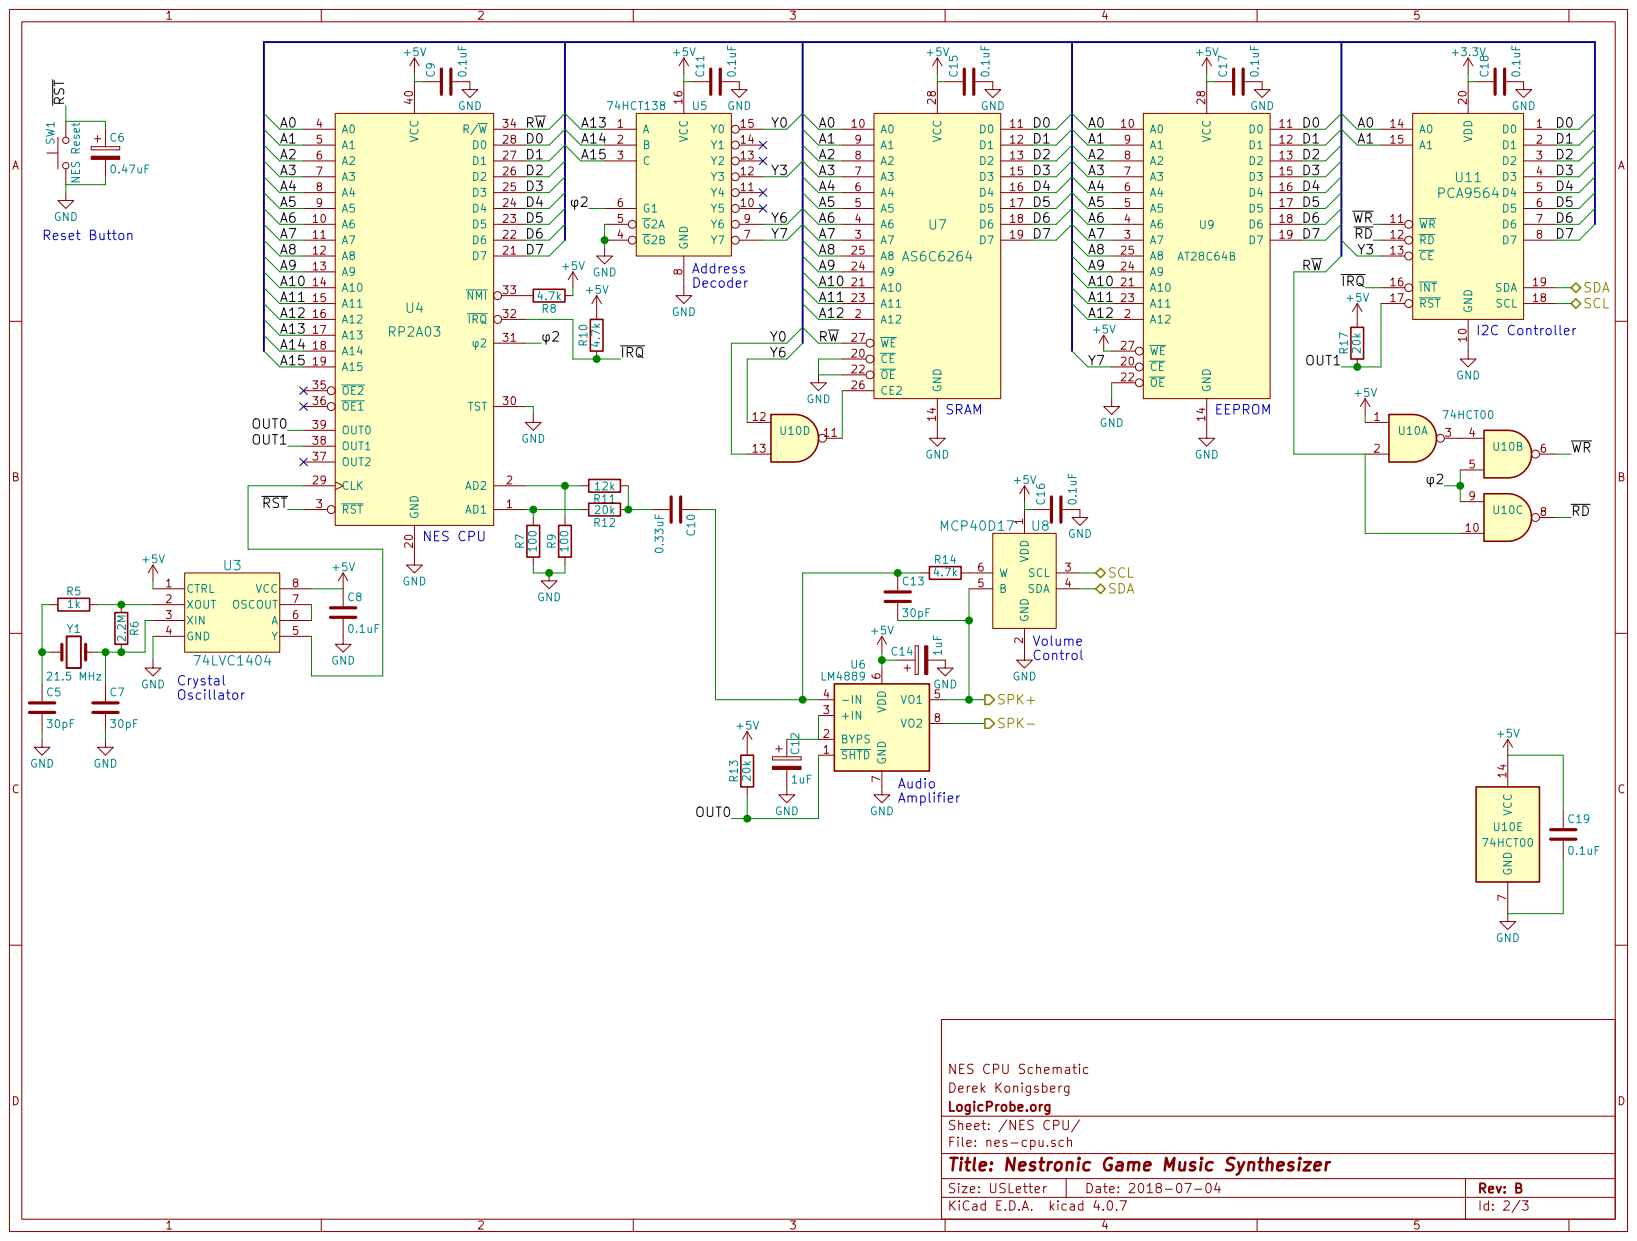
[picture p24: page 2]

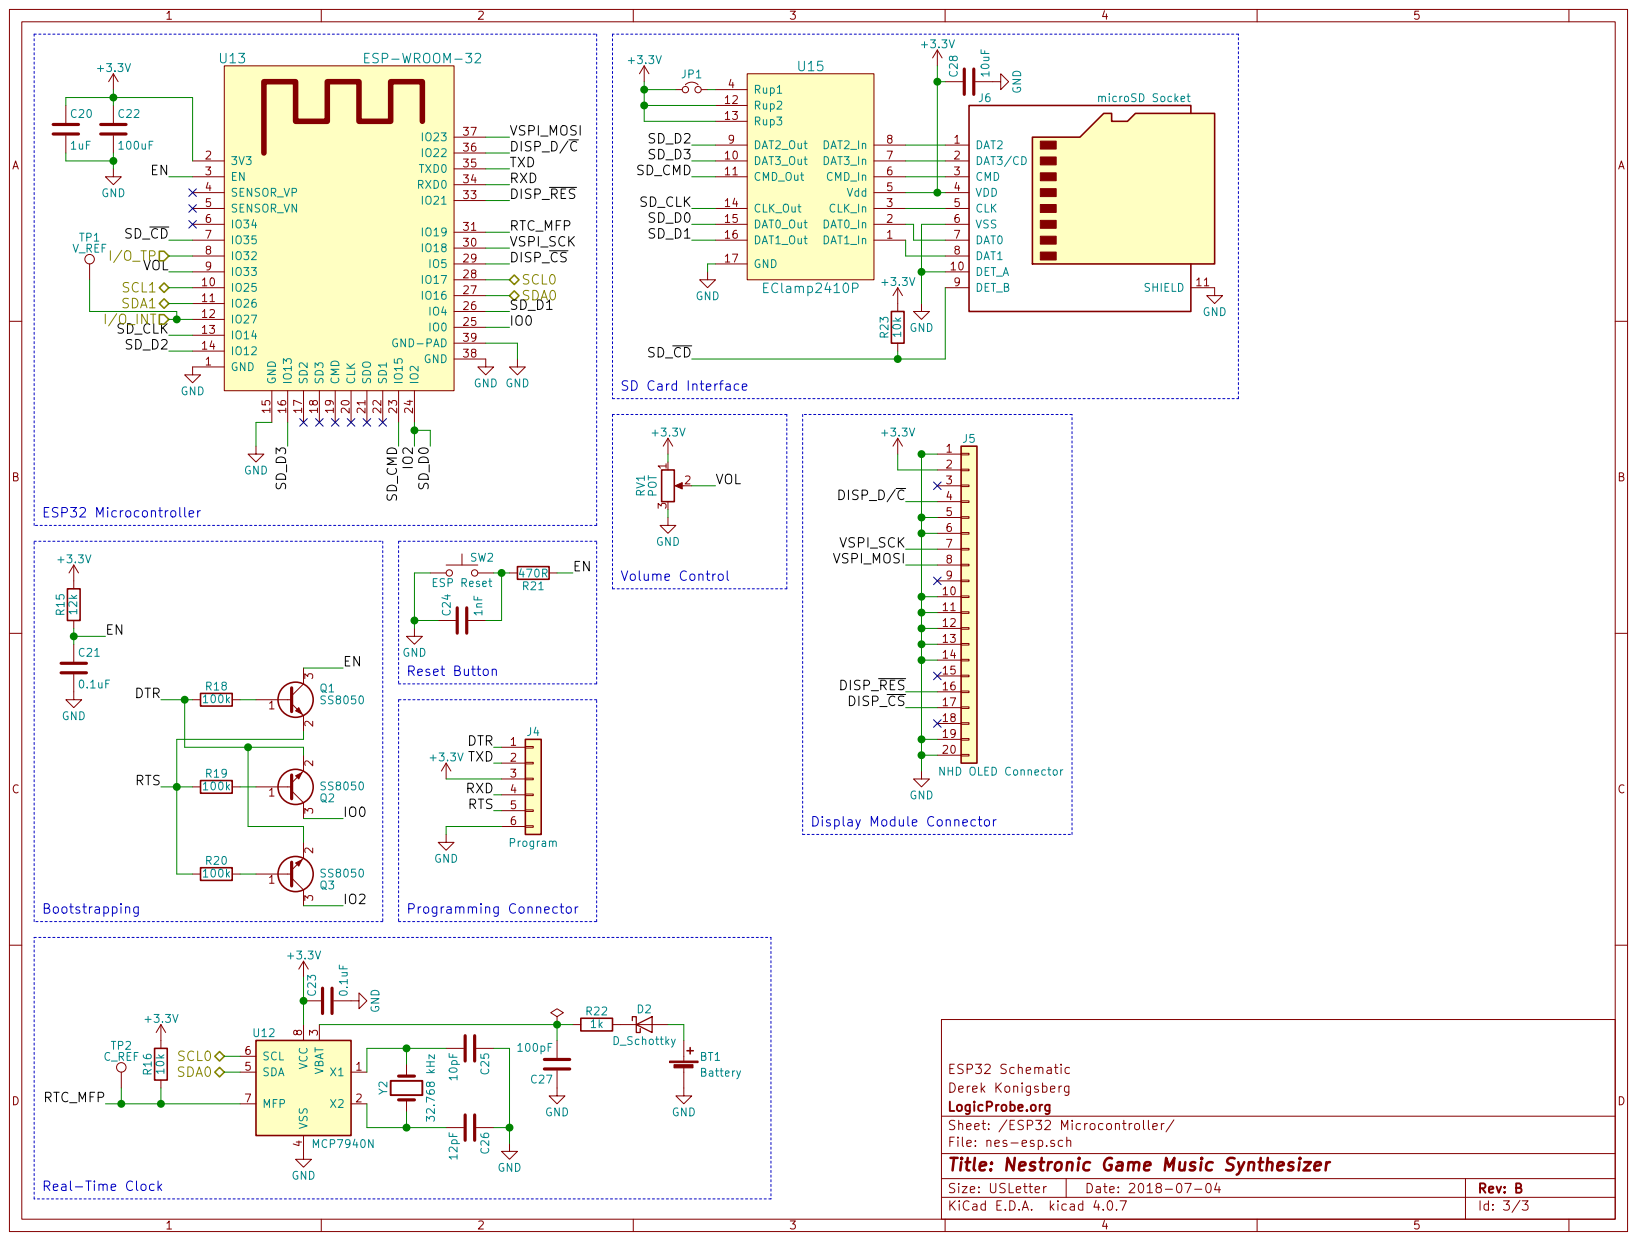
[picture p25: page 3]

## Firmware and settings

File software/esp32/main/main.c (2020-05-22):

#include <freertos/FreeRTOS.h>
#include <freertos/queue.h>
#include <freertos/event_groups.h>
#include <esp_system.h>
#include <esp_event.h>
#include <esp_event_loop.h>
#include <esp_err.h>
#include <esp_log.h>
#include <esp_vfs_fat.h>
#include <nvs_flash.h>
#include <driver/gpio.h>
#include <driver/sdspi_host.h>
#include <driver/i2c.h>
#include <driver/adc.h>
#include <esp_adc_cal.h>
#include <esp_intr_alloc.h>
#include <lwip/err.h>

#include <sys/types.h>
#include <dirent.h>
#include <string.h>
#include <stdbool.h>
#include <math.h>

#include "board_config.h"
#include "settings.h"
#include "time_handler.h"
#include "wifi_handler.h"
#include "i2c_util.h"
#include "sdcard_util.h"
#include "display.h"
#include "board_rtc.h"
#include "keypad.h"
#include "mcp40d17.h"
#include "tsl2591.h"
#include "nes_player.h"
#include "main_menu.h"

static const char *TAG = "main";

// ADC voltage reference
//#define V_REF_TO_GPIO
#define V_REF 1116 // 1.1175V

static xQueueHandle gpio_event_queue = NULL;
static SemaphoreHandle_t rtc_event_mutex = NULL;
static int64_t last_rtc_event = 0;

static float brightness_pct_from_reading(uint16_t reading)
{
    float result;
    if (reading > 1600) {
        result = 1.0F;
    } else {
        result = (9.9323F * logf(reading) + 27.059F) / 100.0F;
    }

    result = (MAX(result, 0.6F) - 0.6F) / 0.4F;
    if (result >= 1.0F) {
        result = 1.0F;
    }
    return result;
}

static void gpio_poll_task(void *pvParameters)
{
    int last_rheo_val = -1;
    int last_cd_level = -1;
    int last_cd_count = 0;

    int index = 0;

    uint8_t brightness_value = 0x9F;
    uint8_t brightness_target = 0x9F;

    while (1) {
        // Check if its been longer than expected since the last RTC alarm
        // interrupt event. These interrupts do not automatically re-trigger if
        // missed, so this code attempts to directly check the GPIO state and
        // recover from that.
        xSemaphoreTake(rtc_event_mutex, portMAX_DELAY);
        int64_t now = esp_timer_get_time();
        if (((now - last_rtc_event) / 1000000LL) > 90) {
            int mfp_level = gpio_get_level(MCP7940_MFP_PIN);
            if (mfp_level == 0) {
                last_rtc_event = now;
                ESP_LOGW(TAG, "RTC alarm active on GPIO poll");
                uint32_t gpio_num = (uint32_t) MCP7940_MFP_PIN;
                xQueueSend(gpio_event_queue, &gpio_num, 0);
            }
        }
        xSemaphoreGive(rtc_event_mutex);

        if (index == 0) {
            // Check the volume control and adjust the amplifier volume
            int val = adc1_get_raw(ADC1_VOL_PIN);
            int rheo_val = val >> 5;
            if (last_rheo_val < 0 || abs(rheo_val - last_rheo_val) > 1) {
                i2c_mutex_lock(I2C_P0_NUM);
                mcp40d17_set_wiper(I2C_P0_NUM, 0x7F & rheo_val);
                i2c_mutex_unlock(I2C_P0_NUM);
                ESP_LOGI(TAG, "Set volume: %d", rheo_val);
                last_rheo_val = rheo_val;
            }

            // Check the ambient light level and adjust the display brightness
            uint16_t ch0_val = 0;
            uint16_t ch1_val = 0;
            i2c_mutex_lock(I2C_P1_NUM);
            bool ch_valid = (tsl2591_get_full_channel_data(I2C_P1_NUM, &ch0_val, &ch1_val) == ESP_OK);
            i2c_mutex_unlock(I2C_P1_NUM);
            if (ch_valid) {
                float pct = brightness_pct_from_reading(ch1_val);
                brightness_target = (uint8_t)(roundf(UINT8_MAX * pct));
            }

            // Check the SD card detect pin
            int level = gpio_get_level(SDMMC_CD);
            if (last_cd_level < 0 || last_cd_level != level) {
                last_cd_level = level;
                last_cd_count = 0;
            } else if (last_cd_count < 3) {
                last_cd_count++;
            }
            if (last_cd_count == 3) {
                last_cd_count++;
                if (last_cd_level == 0) {
                    ESP_LOGI(TAG, "SD/MMC Card Inserted");
                    if (sdcard_mount("/sdcard") != ESP_OK) {
                        display_message("Error", "Could not read SD card", NULL, " OK ");
                    }
                } else if (sdcard_is_mounted()) {
                    ESP_LOGI(TAG, "SD/MMC Card Ejected");
                    sdcard_unmount();
                }
            }
        }

        if (brightness_value != brightness_target) {
            if (brightness_value < brightness_target) {
                brightness_value++;
            } else if (brightness_value > brightness_target) {
                brightness_value--;
            }
            main_menu_brightness_update(brightness_value);

            vTaskDelay(10 / portTICK_RATE_MS);

            index++;
            if (index >= 10) {
                index = 0;
            }
        } else {
            vTaskDelay(100 / portTICK_RATE_MS);
            index = 0;
        }
    }
}

static void gpio_queue_task(void *arg)
{
    uint32_t io_num;
    for(;;) {
        if(xQueueReceive(gpio_event_queue, &io_num, portMAX_DELAY)) {
            if (io_num == MCP7940_MFP_PIN) {
                xSemaphoreTake(rtc_event_mutex, portMAX_DELAY);
                if (board_rtc_int_event_handler() == ESP_OK) {
                    last_rtc_event = esp_timer_get_time();
                }
                xSemaphoreGive(rtc_event_mutex);
            }
            else if (io_num == TCA8418_INT_PIN) {
                keypad_int_event_handler();
            }
            else {
                ESP_LOGI(TAG, "GPIO[%d] intr, val: %d", io_num, gpio_get_level(io_num));
            }
        }
    }
}

static void IRAM_ATTR gpio_isr_handler(void *arg)
{
    uint32_t gpio_num = (uint32_t) arg;
    xQueueSendFromISR(gpio_event_queue, &gpio_num, NULL);
}

static void adc_input_init(void)
{
    ESP_ERROR_CHECK(adc1_config_width(ADC_WIDTH_BIT_12));
    ESP_ERROR_CHECK(adc1_config_channel_atten(ADC1_VOL_PIN, ADC_ATTEN_DB_11));
}

static void gpio_isr_init(void)
{
    gpio_event_queue = xQueueCreate(10, sizeof(uint32_t));
    xTaskCreate(gpio_queue_task, "gpio_queue_task", 2048, NULL, 10, NULL);
    ESP_ERROR_CHECK(gpio_install_isr_service(0 /*ESP_INTR_FLAG_DEFAULT*/));
}

static void rtc_init_helper(void)
{
    ESP_ERROR_CHECK(board_rtc_init());
    gpio_isr_handler_add(MCP7940_MFP_PIN, gpio_isr_handler, (void*)MCP7940_MFP_PIN);
}

static void keypad_init_helper(void)
{
    if (keypad_init() == ESP_OK) {
        gpio_isr_handler_add(TCA8418_INT_PIN, gpio_isr_handler, (void*)TCA8418_INT_PIN);
    } else {
        ESP_LOGE(TAG, "Unable to initialize keypad");
    }
}

static void light_sensor_init_helper(void)
{
    i2c_mutex_lock(I2C_P1_NUM);
    do {
        if (tsl2591_init(I2C_P1_NUM) != ESP_OK) {
            ESP_LOGE(TAG, "Unable to initialize light sensor");
            break;
        }
        if (tsl2591_enable(I2C_P1_NUM) != ESP_OK) {
            ESP_LOGE(TAG, "Unable to enable light sensor");
            break;
        }
    } while(0);
    i2c_mutex_unlock(I2C_P1_NUM);
}

void app_main(void)
{
    esp_err_t ret;

    ret = nvs_flash_init();
    if (ret == ESP_ERR_NVS_NO_FREE_PAGES) {
        ESP_ERROR_CHECK(nvs_flash_erase());
        ret = nvs_flash_init();
    }
    ESP_ERROR_CHECK(ret);

    ESP_LOGI(TAG, "Nestronic System Firmware");
    ESP_LOGI(TAG, "-------------------------");

    rtc_event_mutex = xSemaphoreCreateMutex();
    if (!rtc_event_mutex) {
        ESP_LOGE(TAG, "Unable to create RTC event mutex");
        ESP_ERROR_CHECK(ESP_ERR_NO_MEM);
    }

#ifdef V_REF_TO_GPIO
    // ADC calibration
    ret = adc2_vref_to_gpio(ADC2_VREF_PIN);
    if (ret == ESP_OK){
        ESP_LOGI(TAG, "V_REF routed to GPIO27");
    } else {
        ESP_LOGE(TAG, "Failed to route V_REF");
    }
    vTaskDelay(60000 / portTICK_RATE_MS);
#endif

    // Initialize I2C port 0 (on-board devices)
    ESP_ERROR_CHECK(i2c_init_master_port0());

    // Initialize I2C port 1 (input board devices)
    ESP_ERROR_CHECK(i2c_init_master_port1());

    // Initialize the display, don't fail on errors
    ret = display_init();
    if (ret != ESP_OK) {
        ESP_LOGE(TAG, "Unable to initialize display");
    }

    // Show the startup logo
    display_draw_logo();

    // Initialize the ADC inputs
    adc_input_init();

    // Initialize the SD card interface
    ESP_ERROR_CHECK(sdcard_init());

    // Initialize the GPIO ISR and event queue, needed for
    // RTC and keypad event handling.
    gpio_isr_init();

    // Initialize the external RTC chip
    rtc_init_helper();

    // Initialize the system time
    ESP_ERROR_CHECK(time_handler_init());

    // Initialize the WiFi interface
    tcpip_adapter_init();
    ESP_ERROR_CHECK(wifi_handler_init());

    // Initialize the keypad controller, don't fail on errors
    keypad_init_helper();

    // Initialize the light sensor, don't fail on errors
    light_sensor_init_helper();

    // Initialize the VGM player task
    ESP_ERROR_CHECK(nes_player_init());

    // Show the menu system
    vTaskDelay(1000 / portTICK_RATE_MS);
    main_menu_start();

    // Start the task that polls certain input pins
    xTaskCreate(gpio_poll_task, "gpio_poll_task", 4096, NULL, 5, NULL);
}

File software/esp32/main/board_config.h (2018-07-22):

/*
 * Hardware configuration constants
 */

#ifndef BOARD_CONFIG_H
#define BOARD_CONFIG_H

#include <driver/gpio.h>
#include <driver/i2c.h>
#include <driver/adc.h>
#include <driver/spi_common.h>

/* Pin mapping for SD card in SD/MMC mode */
#define SDMMC_CMD                  GPIO_NUM_15
#define SDMMC_CLK                  GPIO_NUM_14
#define SDMMC_D0                   GPIO_NUM_2
#define SDMMC_D1                   GPIO_NUM_4
#define SDMMC_D2                   GPIO_NUM_12
#define SDMMC_D3                   GPIO_NUM_13
#define SDMMC_CD                   GPIO_NUM_35

/* Pin mapping for display module */
#define SSD1322_MOSI               GPIO_NUM_23
#define SSD1322_SCK                GPIO_NUM_18
#define SSD1322_CS                 GPIO_NUM_5
#define SSD1322_DC                 GPIO_NUM_22
#define SSD1322_RST                GPIO_NUM_21
#define SSD1322_SPI_HOST           VSPI_HOST

/* Pin mapping and parameters for I2C port 0 (on-board devices) */
#define I2C_P0_SCL_IO              GPIO_NUM_17
#define I2C_P0_SDA_IO              GPIO_NUM_16
#define I2C_P0_NUM                 I2C_NUM_0
#define I2C_P0_TX_BUF_DISABLE      0
#define I2C_P0_RX_BUF_DISABLE      0
#define I2C_P0_FREQ_HZ             400000

/* Pin mapping and parameters for I2C port 1 (input board devices) */
#define I2C_P1_SCL_IO              GPIO_NUM_25
#define I2C_P1_SDA_IO              GPIO_NUM_26
#define I2C_P1_NUM                 I2C_NUM_1
#define I2C_P1_TX_BUF_DISABLE      0
#define I2C_P1_RX_BUF_DISABLE      0
#define I2C_P1_FREQ_HZ             400000

/* MCP7940 RTC Interrupt Pin */
#define MCP7940_MFP_PIN            GPIO_NUM_19

/* TCA8418 Keypad Controller Interrupt Pin */
#define TCA8418_INT_PIN            GPIO_NUM_27

/* ADC2 Voltage Reference Pin for calibration */
#define ADC2_VREF_PIN              GPIO_NUM_27

/* ADC1 Volume Control Pin */
#define ADC1_VOL_PIN               ADC1_CHANNEL_5 /* GPIO33 */

/* Input Board Touch Sensor Pin */
#define TOUCH_PAD_PIN              TOUCH_PAD_NUM9 /* GPIO32 */

/* Input Board button codes */
#define KEYPAD_BUTTON_UP           105
#define KEYPAD_BUTTON_DOWN         106
#define KEYPAD_BUTTON_LEFT         107
#define KEYPAD_BUTTON_RIGHT        108
#define KEYPAD_BUTTON_SELECT       109
#define KEYPAD_BUTTON_START        110
#define KEYPAD_BUTTON_B            111
#define KEYPAD_BUTTON_A            112
#define KEYPAD_TOUCH               200

/* Misc constants */
#define MENU_TIMEOUT_MS            30000

#endif /* BOARD_CONFIG_H */

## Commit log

2018-06-15 Imported initial schematics and code for the project
    [BU2032SM-BT-GTR.step, CUI_PJ-058AH.step, CUI_PJ-102AH.step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]
2018-06-16 Fixed library references to use KiCad 4 backport of KiCad 5 libraries
    This project is currently implemented in KiCad 4.0.x, and will remain as
    such until KiCad 5 is released and easily available.
    However, there have been a lot of improvements to the component
    libraries since 4.0.x was frozen. As such, this project was originally
    developed with a haphazardly assembled combination of KiCad Git library
    checkouts. To make everything work, some needed to be modified until
    they loaded without errors on KiCad 4.0.x.
    Since then, the KiCad team has released an official backport of the v5
    libraries:
    https://forum.kicad.info/t/kicad-4-0-x-backport-release-of-kicad-v5-library-is-now-available-on-githu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
2018-06-17 Added CAD assets for the input buttons
    [button_4way.f3d, button_4way.step, button_4way.stl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]
2018-06-20 Remove the ambient light sensor from the main board
    Fixes #9
    [nes-cpu.sch, nes-esp.sch, nes.kicad_pcb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]
2018-06-20 Move TP1 over to GPIO27
    This moves the ADC calibration test point from a pin that always has a
    pull-up resistor, to one that only has issues if the input board is
    plugged in.
    Fixes #6
    [nes-esp.sch, nes.kicad_pcb]
2018-06-20 Change amplifier gain resistor from 20k to 4.7k
    In testing, the minimum volume with 10k was still a little bit too loud,
    so going with 4.7k for now. This is easily adjustible in the future
    without any actual board layout changes.
    Fixes #4
    [nes-cpu.sch, nes.kicad_pcb]
2018-06-20 Changed U8 Vdd from 3.3V to 5V
    Had to reroute a few other traces in the process of doing this, and was
    able to remove some vias from a 3.3V line. Also added some stitching
    vias to re-connect the ground plane that changed as a result.
    [nes-cpu.sch, nes.kicad_pcb]
2018-06-21 Change U7 footprint to one that more closely matches the component
    This involved adding a custom SOIC-28 footprint variant for the
    AS6C6264.
    This IC uses what it calls a "28-pin 330 mil SOP" package, which is not
    in the standard libraries. Its closest match is KiCad's SOIC-28W, but it
    is slightly wider and taller. This footprint and 3D model is based on
    using the IC's datasheet and the reference datasheets from KiCad's
    footprint and 3D model to determine small adjustments.
    The replacement footprint is slightly wider, so some routing was
    adjusted. However, it is mostly a drop-in replacement.
    Fixes #1
    [SOIC-28W_8.636x18.491mm_P1.27mm.FCStd, SOIC-28W_8.636x18.491mm_P1.27mm.step, nes-cpu.sch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]
2018-06-21 Create new component to fix Q1/Q2/Q3 pin mapping issues
    Apparently the S8050 included in the KiCad library was for the TO-92
    version of the part, for which the pin mapping was correct. The part
    we're using is a SOT-23, more completely called SS8050, and has
    different specifications. So fixing the issue meant creating a new
    library symbol with the right pin assignments.
    The PCB layout has also been updated to reflect this change.
    Fixes #5
    [nes-esp.sch, nes.kicad_pcb]
2018-06-23 Swap U11 from SOIC to TSSOP footprint
    This was a trivial part change, with quite extensive trace routing
    changes.
    Fixes #2
    [nes-cpu.sch, nes.kicad_pcb]
2018-06-23 Change SRAM address decoding to mirror it onto address $C000
    To support the NES APU's DMC feature, we need sample memory placed
    around address $C000. Since we're only using a tiny portion of our RAM,
    the easiest way is to mirror the RAM onto both $0000 and $C000.
    This can be accomplished with a spare NAND gate already in our circuit,
    and the secondary non-inverting chip enable line of the SRAM chip. The
    idea is that if either Y0 or Y6 is low, then the output of the NAND gate
    will be high, and thus select the chip.
    Fixes #7
    [nes-cpu.sch, nes.kicad_pcb]
2018-06-29 Added TSL2591 component to the input board
    The TSL2591 is an ambient light sensor, replacing the TSL250 originally
    used on the main board. It is much better at detecting light through the
    enclosure.
    Added the component symbol, footprint, and approximate 3D model.
    Integrated the component into the schematic.
    Updated the PCB layout to include the component in the specific location
    where the updated enclosure will have light holes.
    The footprint should be accurate to the datasheet.
    The 3D model is a generic DFN component in the same dimensions as the
    TSL2591, but looks nothing like it.
    Fixes #10
    [AMS_TSL2591.FCStd, AMS_TSL2591.step, nes-input.kicad_pcb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]
2018-06-30 Route the OUT1 line from the RP2A03 to the PCA9564's reset pin
    This change gives the NES CPU control over resetting its I2C controller,
    for improved error recovery and more predictable startup behavior. Also
    added a pull-up resistor, similar to how OUT0 was wired, for a more
    predictable "high" voltage.
    Fixes #8
    [nes-cpu.sch, nes-esp.sch, nes.kicad_pcb]
2018-07-04 Fixed 3D model reference paths in footprints
    This was a fixup that should have been done as part of the project
    reorganization. The only reason it wasn't noticed sooner, was because
    these paths do not affect components already added to the PCB layouts.
2018-07-04 Add center pad to TCA8418 footprint
    This change makes the center pad appear as a grounded pin in the
    netlist, and thus makes the PCB's DRC pass without any warnings.
    It is not actually a functional change, nor is it actually a change to
    any traces in the PCB layout.
    [nes-input.kicad_pcb, nes-input.sch]
2018-07-05 Updated schematic and PCB references for Rev B
    [nes-cpu.sch, nes-esp.sch, nes-input.kicad_pcb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]
2018-07-06 Fixed 12k resistor component data
    [nes-esp.sch]
2018-07-17 Added assets and initial documentation for the project enclosure
    This includes additional 3D models, 3D printing instructions, and a
    bill-of-materials for components not included on the circuit boards.
    [base.stl, bezel.stl, top-speaker-gasket.stl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]
2018-07-22 Basic handling of the I2C controller reset pin
    The rev B hardware connects the 2A03's I2C controller reset pin to OUT1.
    This change makes sure we bring the controller out of reset on startup,
    and keep it out of reset. Eventually we'll want to integrate fault
    handling into the I2C routines, but right now we need just enough to
    mimic previous behavior.
2018-07-22 Initial support for TSL2591 ambient light sensor
    Added basic I2C interface wrapper for interacting with the sensor. Since
    our design lacks a connection to the sensor's interrupt pin, most of the
    interrupt functionality has not been included in the initial interface
    coded.
    Updated the I2C utility code to provide buffer read/write operations,
    and refactored the device-specific code that originally implemented it.
    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
2018-08-01 Use the correct SPI mode for the display
    I have no idea why, exactly, this was originally set to mode 1.
    However, for some unknown reason, setting the SPI mode to 1 worked
    perfectly fine with the display used in all the original tinkering and
    prototyping activities.
    Of course it failed to work at all with any subsequently tested display
    units.
2018-08-21 Added PDF versions of the circuit schematics
2018-08-22 Initial NES and ESP code to handle I2C block data writes
    This is an update to the protocol spec, and the code that
    implements it.
    The new capability being added is the ability to read and write blocks
    of memory in the $C200-DFFF address range. For simplicity of
    implmentation, data can be written up to 256 bytes at a time.
    The purpose of this change is to support loading samples for the NES
    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
2018-09-09 NES APU DMC support for VGM playback
    Adds support for the playback of sample data on the NES APU. This
    includes loading data blocks from the VGM file into the 2A03's RAM, and
    adjusting VGM commands that write to the address register ($4012) to
    correctly point at that data.
    This feature is one of the most complicated parts of VGM playback so
    far, and thus will likely need refactoring for code clarity in the
    future. It is essentially a virtual memory system that uses limited
    static analysis.
    The Nestronic cannot handle this part of the APU/VGM spec by simply
    sending commands to the 2A03 verbatim, like the rest of it. This is
    because the Nestronic does not have the same memory map as a real N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
    [nes.c, vgm_player.c]
2018-09-09 Update u8g2 library to latest master 4dd7a012
    [board.dxf]
2018-09-16 Fix leading zero display on 24-hour time
    [display.c]
2018-09-21 Initial implementation of the alarm clock functionality
    Added a more complete alarm settings UI.
    This reorders some main menu items, and adds a UI flow for setting both
    the alarm time and tune. The tune selection required some cleanup to the
    file picker UI.
    Also did some minor refactoring of the settings code to prevent
    duplication.
    Added controllable repeat behaviors to the VGM player itself, for
    continuous alarm playback.
    Implemented the basic alarm functionality, complete with a 5 minute time
    limit and a 9 minute snooze behavior. The trigger is still rather
    simple, happening when there's a time interrupt for the set time.
    The actual alarm enabled flag is not yet persistent. Its likely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
    [display.c, vgm_player.c]
2018-09-23 Collect RTC power fail timestamp data on startup
    [board_rtc.c, mcp7940.c]
2018-09-23 Added RTC SRAM persistence support for the alarm set flag
    Added functions to read/write to the MCP7940's SRAM region.
    Added code to initialize the MCP7940 SRAM, using the ESP32's MAC address
    as a flag to detect whether it has been initialized previously. This is
    necessary because this region will likely contain random garbage on a
    power-on reset.
    Added code to store the alarm's "set" flag in this SRAM, so its
    persistence is more closely tied to the clock time. This was also done
    since this is a flag we expect a user to regularly fiddle with, and I'd
    rather not wear the flash with this.
    [board_rtc.c, mcp7940.c]
2018-10-08 Initial NSF playback implementation
    This implementation uses the Fake6502 emulator to "run" the code
    contained within an NSF file, captures APU writes, and sends them to the
    NES APU. It does not yet support DPCM, nor does it have any safety
    against a malformed NSF file causing issues. Regular bankswitching is
    supported, but FDS bankswitching is not.
    It started as a proof-of-concept to see if this could be done, and will
    be cleaned up and improved over time.
    [fake6502.c, vgm_player.c]
2018-10-10 Add alarm trigger animation and fix touchpad input
    Added a simple animation of the alarm clock icon, which is now shown
    when the alarm is triggered. This provides visual indication of an alarm
    in progress.
    Also fixed touchpad input, which was probably broken as a side-effect of
    the ESP-IDF 3.1 update. This input is used to trigger the snooze
    function.
    [display.c, keypad.c]
2018-11-18 Update hardware project to support KiCad v5
    This change does all the necessary symbol remapping and file re-saving
    so that KiCad v5 is now cleanly supported going forward. Hopefully there
    are no actual changes of consequence introduced by this diff.
    [nes-cpu.sch, nes-esp.sch, nes-input.kicad_pcb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]
2018-12-27 Updated model files for 3D CAD rebuild
    These updates reflect a rebuild of the Fusion360 CAD model. The updated
    model is slightly shorter, fixes height proportions between the top and
    bottom halves of the shell, and uses millimeters as the primary unit.
    [base.stl, bezel.stl, top-speaker-gasket.stl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]
2018-12-29 Updates to alarm triggering and snooze display
    Changed the routine that detects an alarm trigger so that it's hopefully
    not fooled by time skips. This works by tracking the current and
    previous minute tick values, and comparing them against the alarm set
    time.
    Updated button handling so that an active alarm is only canceled by
    actually pressing the alarm-off button.
    Changed the snooze behavior so that it now shows a unique icon when an
    active alarm is snoozed.
    [display.c]
2019-01-18 Fix issues with settings get functions mishandling a fresh system
    The get functions in the settings module were misbehaving in cases of
    certain error codes that only happen on a fresh system. This change
    rewrites the error handling to use a better pattern and correctly handle
    those cases.
    Also updated all the settings log functions to print more descriptive
    error messages.
2019-04-02 Workaround for missed RTC interrupt issue
    Sometimes the RTC interrupt stops getting processed, which causes the
    clock to stop updating by itself. The most likely cause is that an ISR
    isn't triggered when the RTC MFP pin is low, which means the alarm flag
    is never cleared, and the interrupt is not triggered again. While this
    can happen due to startup timing issues, it has been observed to happen
    at runtime. However, it is extremely rare and nearly impossible to
    reproduce deliberately.
    As an attempted workaround, the last time of the RTC interrupt event will
    now be tracked. If more than 90 seconds passes without an event, the
    GPIO polling task will inject it into the queue as if it had. Since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
    [main.c]
2019-10-11 Set minimum ESP32 revision to 1
    This is what we're using for the project, so no reason to need to ensure
    rev 0 compatibility.
2019-10-20 Add date display and various minor adjustments
    Added development-only code to allow triggering screenshots and alarm
    sequences during development.
    Added timeout and loop break checks to try and avoid alarm animation
    glitches when buttons are pressed during alarms.
    Renamed "tiny" bitmap segment assets to avoid confusion.
    Added code to draw "tiny" segmented numbers and separators.
    Changed positioning and spacing of screen elements to make more room on
    the right side of the time display.
    Added display of the date (MM/DD format) near the time.
    [display.c]
2020-04-09 Check RTC flag clearing result before resetting last update time
    [main.c]
2020-04-16 Redesigned bankswitched NSF playback to cache unloaded banks
    Complex NSF files were having issues with frame underruns, because the
    time necessary to load new ROM blocks from the SD card exceeded the
    available time budget of a single playback frame. This issue could
    compound if blocks got twiddled between ROM banks during playback.
    The first step to solving this issue was to separate loaded data blocks
    from the address layout of the fake 6502. This was done by switching
    from direct addressing of the memory data structure to indirect addressing
    using a series of pointers corresponding to each of the 4k ROM banks.
    The second, and arguably more complex, step was to allow allocating more
    space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
    [nsf_player.c]
2020-05-22 Fix a display brightness overflow issue
    The function that converts an ambient light sensor reading into a
    floating point percentage would sometimes return values greater than
    1.0. This would happen for high input values that were slightly below
    the maximum threshold. As a result of this, the conversion to a display
    brightness value would overflow and make the display dim.
    [main.c]

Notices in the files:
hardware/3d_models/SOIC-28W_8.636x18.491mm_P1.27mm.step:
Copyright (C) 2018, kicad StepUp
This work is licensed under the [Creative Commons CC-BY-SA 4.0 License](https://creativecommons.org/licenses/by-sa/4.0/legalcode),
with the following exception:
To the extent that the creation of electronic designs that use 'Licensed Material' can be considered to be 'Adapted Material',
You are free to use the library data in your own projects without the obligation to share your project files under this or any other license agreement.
